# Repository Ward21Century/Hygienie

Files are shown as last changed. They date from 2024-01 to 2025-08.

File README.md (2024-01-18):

# Hygienie Project

This is the refactored code for hygienie-2022 refactored project that uses the esp-idf framework. This means that source code has been refactored into modules, unit-tests have been written for each module and can be run on the esp32 itself for regression testing, and that project values such as wifi network, password, device id, and sleep duration can be entered in a terminal menu.

## Project layout

```
hygienie_project                      — Application project directory
  - components                 — Components of the application project
    + appdata                  — Module that describes how the data is structured.
    + appgraphics              — Module that uses graphics libary and displays animations
    + appmqtt                  — Module that encapsulates mqtt client
    + appsleep                 — Module that controls esp32 sleep  mode
    + appwifi                  — Module that encapsulates wifi libraries
  + main                       - Main source files of the application project
  - test                       — Test project directory
    - main                       — test main directory for test runner
      + hygienie_unit_test.c   — hygienie test runner.
  Makefile / CMakeLists.txt    - Makefiles of the application project
```

The two projects, main, and test/main, can implement different application behavior when running normally, and when running the unit tests. Top level project is the actual application being developed. Test project included within is a simple application which only runs the unit tests.

## Unit tests for a component

Inside the `testable` component, unit tests are added into `test` directory. `test` directory contains source files of the tests and the component makefile (component.mk / CMakeLists.txt).

```
unit_test
  - components                              - Components of the application project
    - testable
      - include
      - test                                - Test directory of the component
        * component.mk / CMakeLists.txt     - Component makefile of tests
        * test_mean.c                       - Test source file
      * component.mk / CMakeLists.txt       - Component makefile
      * mean.c                              - Component source file
```

When the main application project is compiled, tests are not included. Test project includes the tests by setting `TEST_COMPONENTS` variable in the project makefile.

## Requirements

### Hardware required

* FireBeetle DFR0478, but any esp32 board will work.
* USB cable - USBA/

### Software Requirements
Please look at https://docs.espressif.com/projects/esp-idf/en/latest/esp32/get-started/
for installing esp-idf and https://docs.espressif.com/projects/esp-idf/en/latest/esp32/get-started/linux-macos-setup.html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
for configuring and building project on command line.

It is recommended that you run:
```
. $HOME/esp/esp-idf/export.sh
```
in your terminal.

and create the alias:
```
alias get_idf='. $HOME/esp/esp-idf/export.sh'# Configure the project
```
For the menu_config:

For the test project, you can open the project configuration menu (`idf.py menuconfig`) and explore a few options related to Unity under Component Config, Unity unit testing library.

### Build and flash

As explained above, this example contains two projects: application project and test project.

1. Application project calls an API defined in the component, and displays the results. It is not of much value to run. Application project is provided mainly to illustrate the layout of all the files. If you decide to run this project, the procedure is:

    * Run `idf.py -p PORT flash monitor` in the current directory (`unit_test`).
    * Observe the output: a list of random numbers and their mean value.

2. Test project is responsible for running the tests.

	* Enter `test` directory (`unit_test/test`), and run `idf.py -p PORT flash monitor`.
	* Observe the output: results of test case execution.

See the Getting Started Guide for full steps to configure and use ESP-IDF to build projects.

## Unit Testing

Inside the `testable` component, unit tests are added into `test` directory. `test` directory contains source files of the tests and the component makefile (component.mk / CMakeLists.txt).

```
unit_test
  - components                              - Components of the application project
    - testable
      - include
      - test                                - Test directory of the component
        * component.mk / CMakeLists.txt     - Component makefile of tests
        * test_mean.c                       - Test source file
      * component.mk / CMakeLists.txt       - Component makefile
      * mean.c                              - Component source file
```

When the main application project is compiled, tests are not included. Test project includes the tests by setting `TEST_COMPONENTS` variable in the project makefile.
### Application project output

```
In main application. Collecting 32 random numbers from 1 to 100:
   5   66   86   98   62   66   40   42    7   62
  33   77   40   54    8   75   39   82   73    4
  22    5   72   78   53    1    6   48   23    1
  84   55
Mean: 45
```

### Test project output

```
#### Executing one test by its name #####

Running Mean of an empty array is zero...
/Users/ivan/e/esp-idf/examples/system/unit_test/components/testable/test/test_mean.c:16:Mean of an empty array is zero:PASS

-----------------------
1 Tests 0 Failures 0 Ignored
OK

Running Mean of an empty array is zero...
/home/user/esp/esp-idf/examples/system/unit_test/components/testable/test/test_mean.c:15:Mean of an empty array is zero:PASS
Test ran in 16ms

-----------------------
1 Tests 0 Failures 0 Ignored
OK
Enter next test, or 'enter' to see menu
```

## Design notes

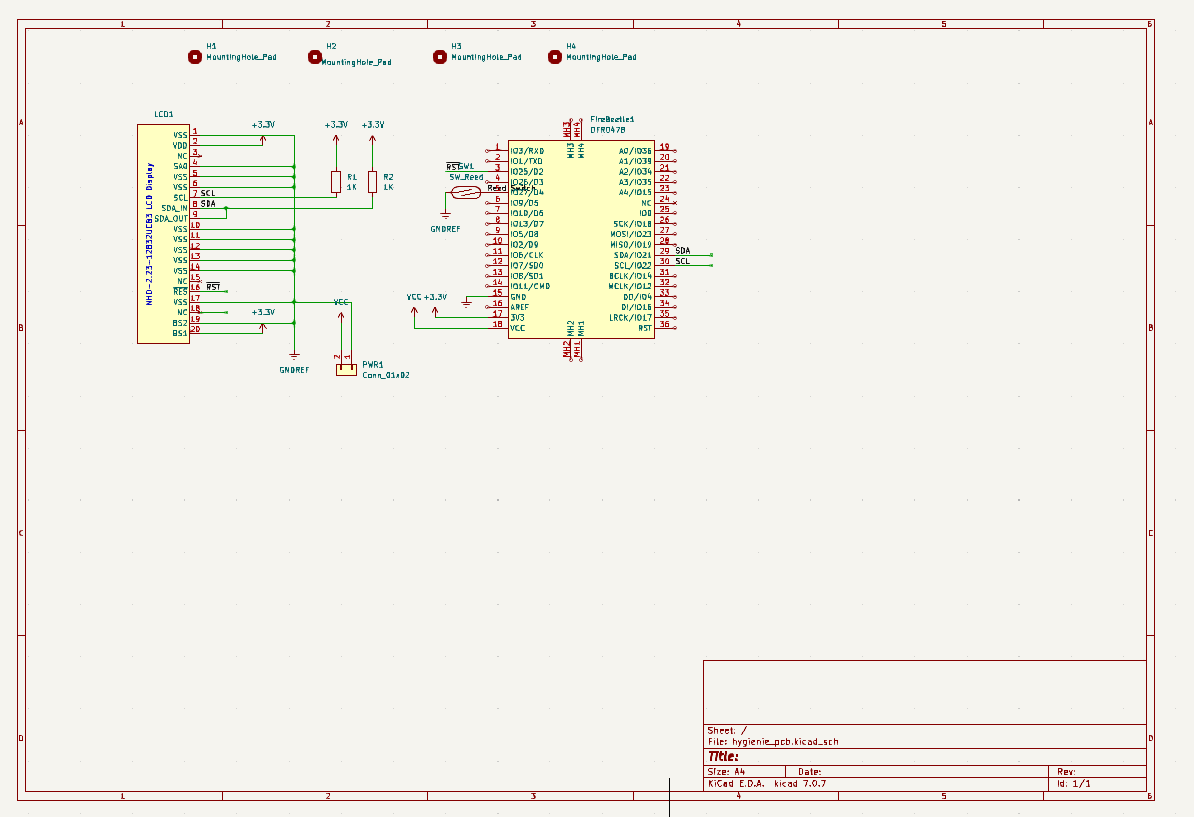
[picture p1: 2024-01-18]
docs/PCB/Schematic/Hygienie Schematic.png

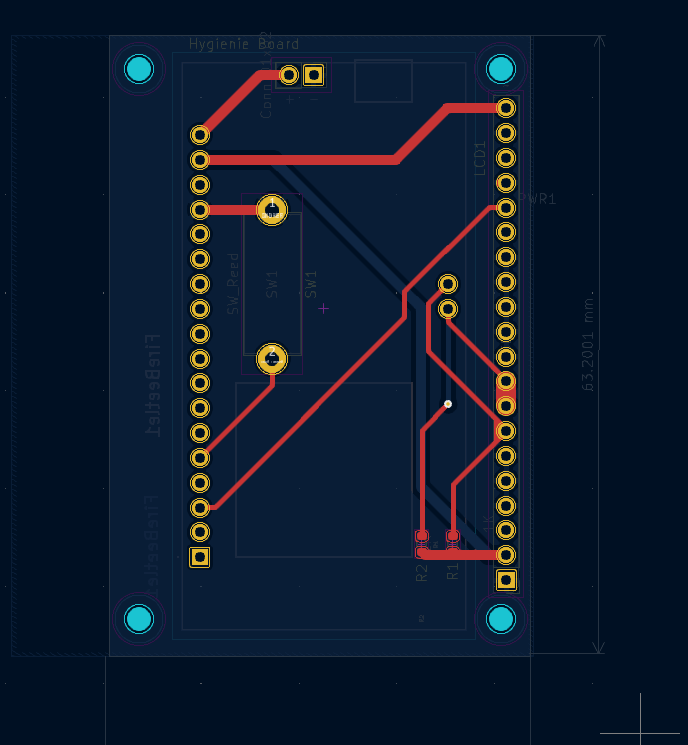
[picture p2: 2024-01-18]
docs/PCB/Layout/Hygienie_Version3_PCB.png

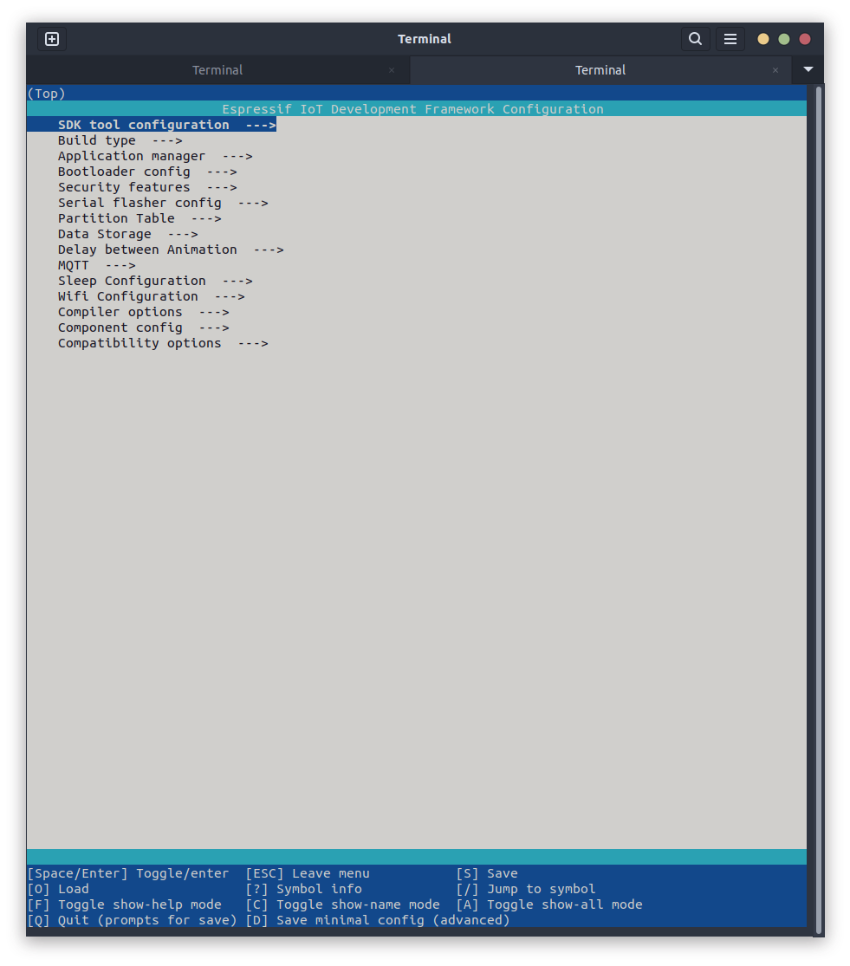
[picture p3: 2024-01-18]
docs/menu_config.png

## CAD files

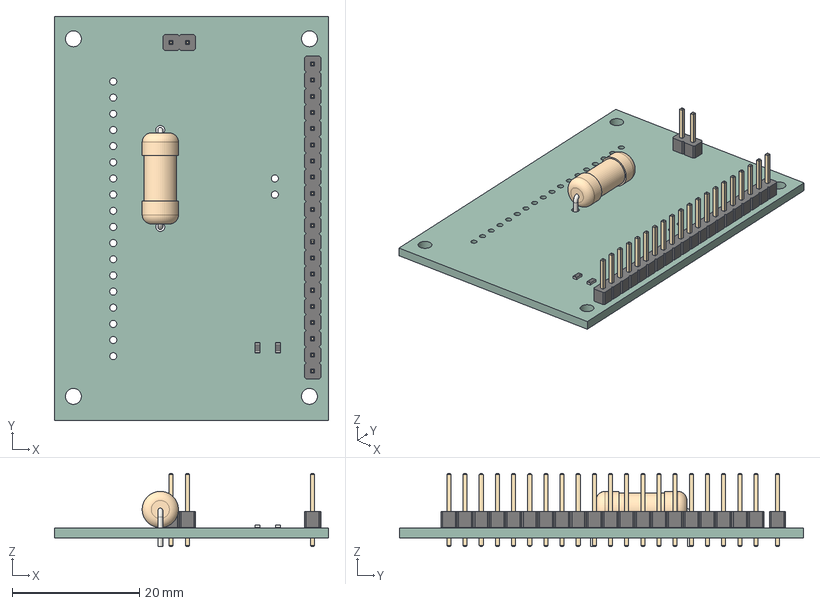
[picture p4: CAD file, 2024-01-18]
docs/PCB/KiCad Project Files/hygienie_pcb/hygienie_pcb.step
43.1 x 63.5 x 11.5 mm
_autosave-hygienie_pcb PCB

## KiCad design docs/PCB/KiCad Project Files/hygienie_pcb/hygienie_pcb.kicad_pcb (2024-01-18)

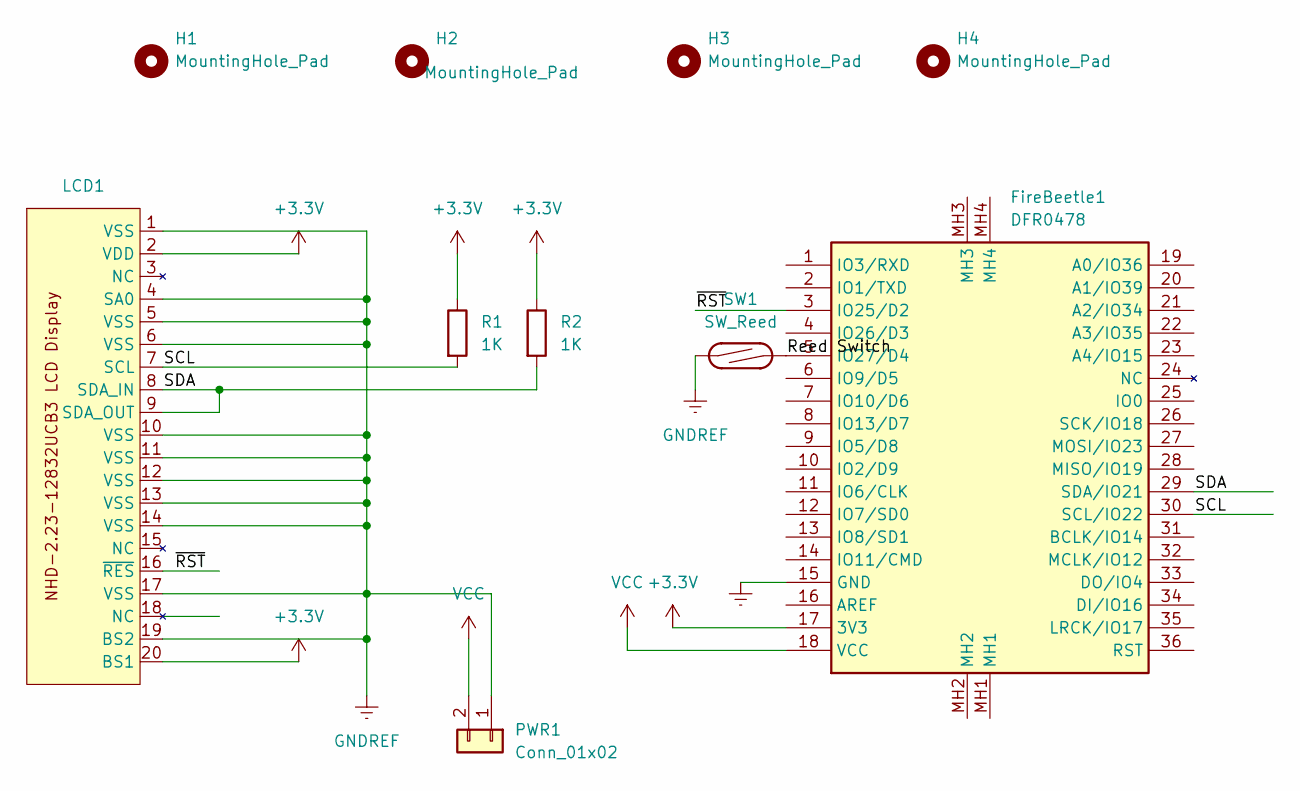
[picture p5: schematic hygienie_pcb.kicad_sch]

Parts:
FireBeetle1: DFR0478; FIREBEETLE_ESP32_Hygienie_Mod; Manufacturer_Part_Number DFR0478
H1, H2, H3, H4: MountingHole_Pad; MountingHole_2.5mm
LCD1: PinHeader_1x20_P2.54mm_Vertical
PWR1: Conn_01x02; PinHeader_1x02_P2.54mm_Vertical
R1, R2: 1K; R_0603_1608Metric
SW1: SW_Reed; R_Axial_DIN0614_L14.3mm_D5.7mm_P15.24mm_Horizontal

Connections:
+3.3V: FireBeetle1.17 (3V3), LCD1.2 (VDD), LCD1.20 (BS1), R1.1, R2.1
/Reed Switch: FireBeetle1.5 (IO27/D4), SW1.2
/SCL: FireBeetle1.30 (SCL/IO22), LCD1.7 (SCL), R1.2
/SDA: FireBeetle1.29 (SDA/IO21), LCD1.8 (SDA_IN), LCD1.9 (SDA_OUT), R2.2
/~RST: FireBeetle1.3 (IO25/D2), LCD1.16 (~RES)
GNDREF: FireBeetle1.15 (GND), LCD1.1 (VSS), LCD1.4 (SA0), LCD1.5 (VSS), LCD1.6 (VSS), LCD1.10 (VSS), LCD1.11 (VSS), LCD1.12 (VSS), LCD1.13 (VSS), LCD1.14 (VSS), LCD1.17 (VSS), LCD1.19 (BS2), PWR1.1, SW1.1
VCC: FireBeetle1.18 (VCC), PWR1.2

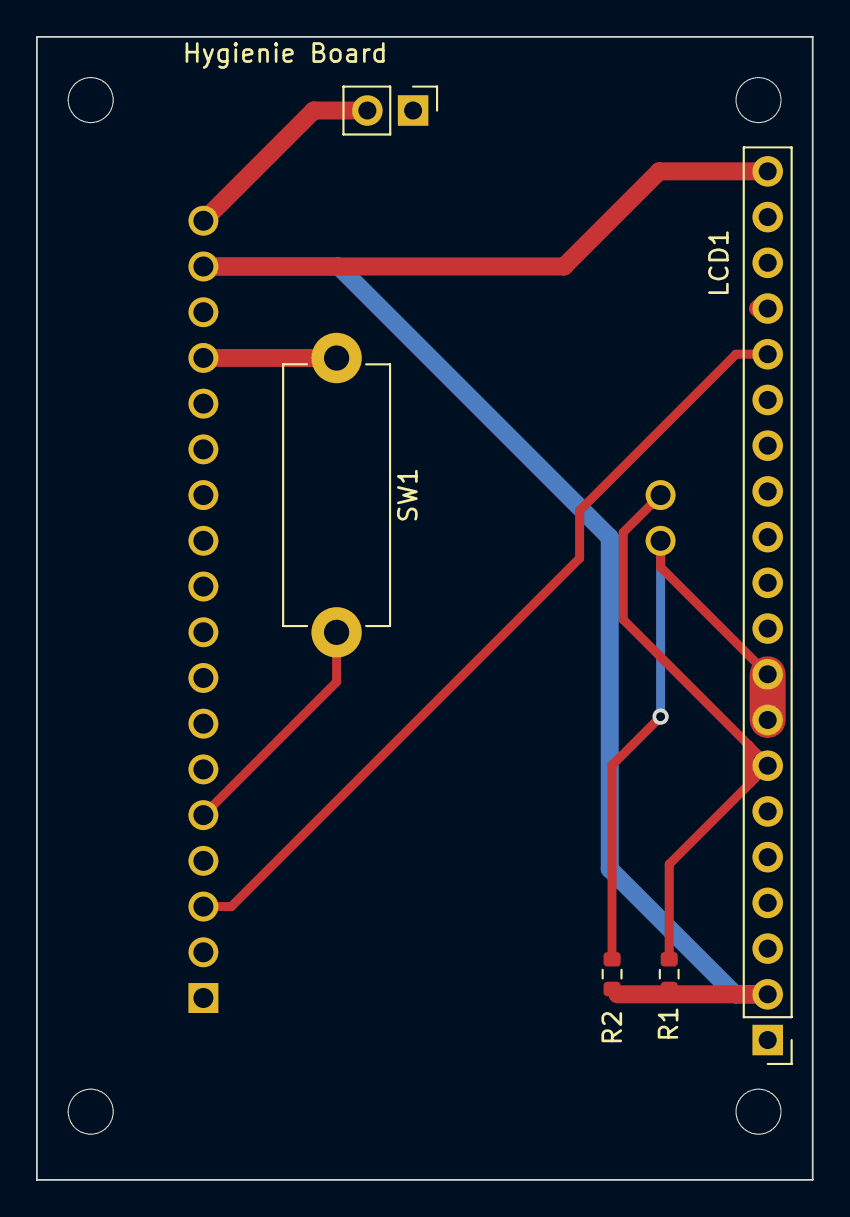
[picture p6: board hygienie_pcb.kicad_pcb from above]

Board: 2 copper layers, 43.1 x 63.5 mm, 10 parts (1 on the bottom side), 7 nets.

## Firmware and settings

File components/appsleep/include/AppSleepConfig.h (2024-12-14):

#include <stdio.h>
#include <string.h>
#include <stdlib.h>
#include <time.h>
#include <sys/time.h>
#include "sdkconfig.h"
#include "soc/soc_caps.h"
#include "freertos/FreeRTOS.h"
#include "freertos/task.h"
#include "esp_sleep.h"
#include "esp_log.h"
#include "driver/rtc_io.h"
#include "soc/rtc.h"
#include <inttypes.h>


#include "soc/sens_periph.h"

#ifdef CONFIG_DEEP_SLEEP_TIMER
#define DEEP_SLEEP_TIMER CONFIG_DEEP_SLEEP_TIMER
#endif

#ifdef CONFIG_IDF_TARGET_ESP32C3
#define DEFAULT_WAKEUP_PIN      CONFIG_EXAMPLE_GPIO_WAKEUP_PIN
#ifdef CONFIG_EXAMPLE_GPIO_WAKEUP_HIGH_LEVEL
#define DEFAULT_WAKEUP_LEVEL    ESP_GPIO_WAKEUP_GPIO_HIGH
#else
#define DEFAULT_WAKEUP_LEVEL    ESP_GPIO_WAKEUP_GPIO_LOW
#endif
#endif

#ifdef CONFIG_EXAMPLE_ULP_TEMPERATURE_WAKEUP
#if CONFIG_IDF_TARGET_ESP32

// Adding RTC_DATA_ATTR for sleep enter time for a later time
/*
 * Offset (in 32-bit words) in RTC Slow memory where the data is placed
 * by the ULP coprocessor. It can be chosen to be any value greater or equal
 * to ULP program size, and less than the CONFIG_ESP32_ULP_COPROC_RESERVE_MEM/4 - 6,
 * where 6 is the number of words used by the ULP coprocessor.
 */
#define ULP_DATA_OFFSET    0

// TODO: Add ULP temperature monitoring program to Appsleep module.
/**
 * @brief Start ULP temperature monitoring program
 *
 * This function loads a program into the RTC Slow memory and starts up the ULP.
 * The program monitors on-chip temperature sensor and wakes up the SoC when
 * the temperature goes lower or higher than certain thresholds.
 */
// TODO: Add ULP temperature monitoring program to Appsleep module. Will comment out until feature is needed.
//static void start_ulp_temperature_monitoring(void);

/**
 * @brief Utility function which reads data written by ULP program
 *
 * @param offset offset from ULP_DATA_OFFSET in RTC Slow memory, in words
 * @return lower 16-bit part of the word writable by the ULP
 */
static inline uint16_t ulp_data_read(size_t offset)
{
    return RTC_SLOW_ATTR[ULP_DATA_OFFSET + offset] & 0xffff;
}

/**
 * @brief Utility function which writes data to be ready by ULP program
 *
 * @param offset offset from ULP_DATA_OFFSET in RTC Slow memory, in words
 * @param value lower 16-bit part of the word to be stored
 */
static inline void ulp_data_write(size_t offset, uint16_t value)
{
    RTC_SLOW_ATTR[ULP_DATA_OFFSET + offset] = value;
}
#endif // CONFIG_IDF_TARGET_ESP32
#endif // CONFIG_EXAMPLE_ULP_TEMPERATURE_WAKEUP

#ifdef CONFIG_EXAMPLE_TOUCH_WAKEUP
#ifdef CONFIG_IDF_TARGET_ESP32
#if CONFIG_TOUCH_THRESHOLD
#endif
#endif
#endif

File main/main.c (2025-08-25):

#include <stdio.h>
#include <stdlib.h>
#include <esp_intr_types.h>
#include "esp_system.h"
#include "testable.h"
#include "esp_wifi.h"
#include "driver/adc.h"
#include "AppGraphics.h"
#include "Appmqtt.h"
#include "AppSleep.h"
#include "appwifi.h"

static const char *TAG = "App Main";
RTC_DATA_ATTR static uint8_t initialized = 0; 
void app_main() {
    AppSleepInit();
    esp_sleep_wakeup_cause_t wakeupCause = AppSleepGetWakeUpCause();
    ESP_LOGI(TAG, "Wake-up cause: %" PRIu32, (uint32_t)wakeupCause);
    if (!initialized) {
        /* Perform initialization tasks here (Wi-Fi, peripherals, etc.) */
        ESP_LOGI(TAG, "Initialization values: %" PRIu8, initialized);
        ESP_LOGI(TAG, "System initializing...");
        /* Perform initialization tasks here (Wi-Fi, peripherals, etc.) */
        initialized = 1;
       /* It's a good idea to synchronize time after initialization */
        AppGraphicsAnimationCycle();
        AppWifiStart();
        AppMqttInitNTPAndSyncTime();
        AppWifiDisconnect();
        ESP_LOGI(TAG, "System initialized.");
    }
    switch (wakeupCause) {

        case ESP_SLEEP_WAKEUP_TIMER:
            ESP_LOGI(TAG, "Wake up from sleep timer.\r\n");
            AppSleepLog();
            ESP_LOGI(TAG, "Woke up from timer.");
            if (AppMqttGetNumoffLineReadingCount() > 0 ) 
            {
                AppWifiStart();
                AppMqttSendData();
                AppMqttInitNTPAndSyncTime();
                AppWifiDisconnect();
                ESP_LOGI(TAG, "Data sent after wake up.");
            }
            break;

         case ESP_SLEEP_WAKEUP_EXT0:
            ESP_LOGI(TAG, "Wake up from external GPIO 27 (reed switch)");
            AppMqttAddTime();
            AppGraphicsAnimationCycle();
            if (AppMqttGetNumoffLineReadingCount() >= MAX_OFFLINE_READINGS) {
                AppWifiStart();
                AppMqttSendData();
                AppMqttInitNTPAndSyncTime();
                AppWifiDisconnect();
            }
            break;

        case ESP_SLEEP_WAKEUP_UNDEFINED:
            ESP_LOGE(TAG, "Error: Unhandled wake up cause: %" PRIu32, (uint32_t)wakeupCause);
            break;
        default:
            ESP_LOGI(TAG, "ERROR with wake up cause\n");
    }
    ESP_LOGI(TAG, "Going to Sleep\r\n");

    AppSleepConfigureGpioForSleep();
    AppSleepGoToDeepSleep();
}

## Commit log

2023-02-20 Added AppSleep. This allows the app to sleep by a touchpad and a timer.
2023-03-06 Added a delay between animations just like what arduino has.
2023-05-24 Added test cases to appgraphics and additional driver to appgraphics.
2023-05-30 Fiddled with pdMS_TO_TICKS so connection for mqtt doesn't time out.
    [AppSleep.c]
2023-08-23 Modified driver for new display.
2023-09-24 Added PCB schematic, gerber files, and screenshots of both schematic and PCB layout.
    [hygienie_pcb-B_Cu.gbr, hygienie_pcb-B_Mask.gbr, hygienie_pcb-B_Paste.gbr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]
2023-11-22 Fixed bug where grpahics was still displayed incorrectly.
    [AppGraphics.c, AppGraphics.h, main.c]
2024-03-11 Added some user-configurable values at run-time, such as mqtt_uri and device id.
2024-03-11 Reorganized flow of code in main.c for better readability.
2024-03-25 Fixed timestamp issue. Cleaned up unused variables.
    [AppSleep.c, main.c]
2024-04-05 Forked u8g2-hal-esp-idf to alter i2c_clk_speed to 100000 Hz and altered .gitmodules so it's faster.
2024-04-05 Changed file names appmqtt and appdata so that it conforms with camel case style.
2024-05-30 Raised minimum threshold for touchpad to wake up to prevent false postives.
    [AppSleep.c]
2024-06-10 Rewrote AppSleep so that GPIO takes an interrupt rather than apptouch.
2024-08-05 Created new pin that enables LCD converter. Also configured gpio pins for normal opearation and for deep sleep to minimize power consumption
2024-08-25 WIP: Still in debugging mode. Changed touch_pad pin to an external wake up pin to conserve more power.
2025-08-25 Added some debug logs to make sure GPIO for REED SWITCH is pulled up
2025-08-25 Renamed pin 27 to ites respective macro
